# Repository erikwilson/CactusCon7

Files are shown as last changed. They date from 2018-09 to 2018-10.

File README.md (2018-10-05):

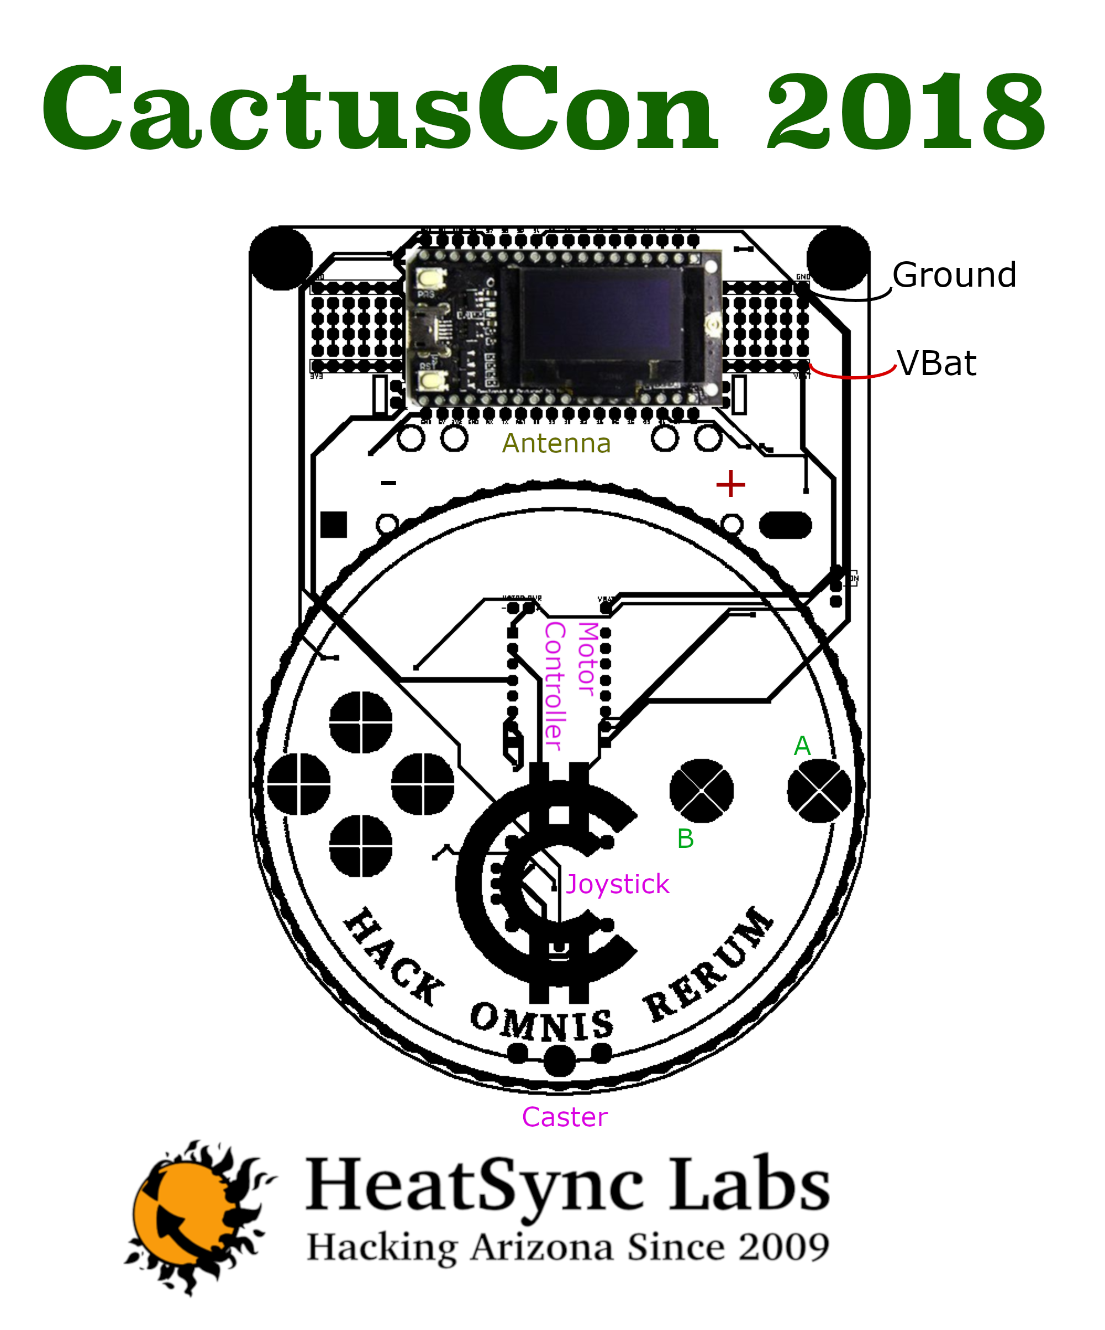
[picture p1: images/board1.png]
CactusCon 2018


# CactusCoin

## Hack All The Things

This year's badge is based around a TTGO LoRa OLED ESP32 and contains six capacitive 'buttons' driven from four sensor inputs (classic [n choose floor(n/2)](http://www.wolframalpha.com/input/?i=n+choose+floor(n%2F2)) problem). The ESP32 sports 4MB of programmable flash, WiFi, Bluetooth, and a dual core 240MHz processor, mounted on a board with a 433MHz long range radio, display, and lipo charger. It requires a single 18650 lithium ion rechargable battery. Optional circuitry supports a motor driver which operates on the same lines as the OLED by disabling screen controls when using the motor controller.  Add in some d-pad action, motors, wheels, and a jöystick. It has an access point, captive portal, websockets, and hidden secrets. The firmware was written using Arduino. It’s completely hackable. Wear it, play with it, use it, modify it, break it, learn from it.

## Volunteering

Every year countless hackers toil for endless hours to bring you this most exquisite and bespoke artisanal CactusCon experience. Please email badge@cactuscon.com if you wish to sacrifice yourself and contribute to the great process. Help build the global hacker community!

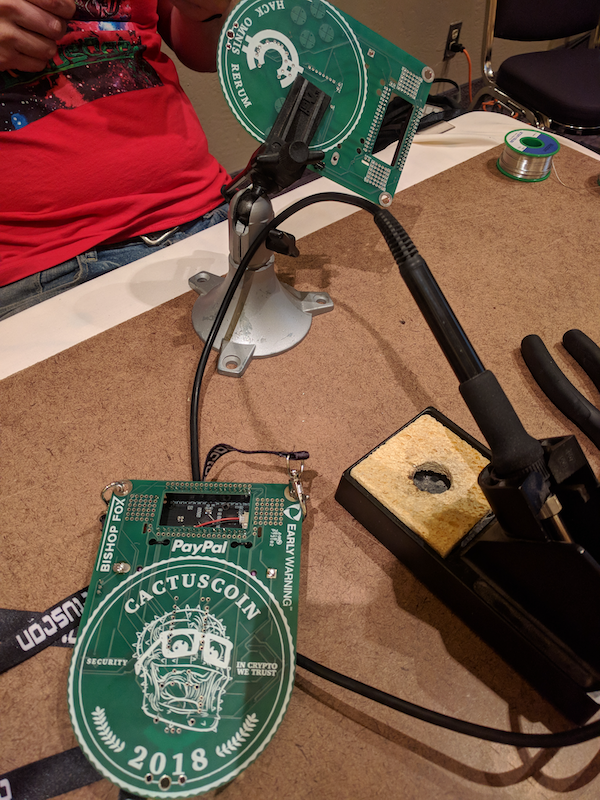
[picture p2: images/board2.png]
Volunteer


## ̶B̶u̶g̶s̶ ̶ Features and Pull Requests

Feel free to submit issues, or even better submit a pull request with extra functionality!

The coin provides a swiss army knife of utility, what can you make with it?

Pull Request

## Parts

#### basic

* 1 [TTGO LoRa OLED ESP32](https://www.aliexpress.com/item/2pcs-sets-TTGO-LORA-SX1278-ESP32-0-96-OLED-16-Mt-bytes-128-Mt-bit-433Mhz/32832523252.html)
* 2 x [18 pos female header](https://www.digikey.com/product-detail/en/PPTC181LFBN-RC/S7016-ND/810156/?itemSeq=272349209)
* 1 [battery holder](https://www.digikey.com/product-detail/en/BH-18650-PC/BH-18650-PC-ND/3029216/?itemSeq=272342283)
* 1 [switch](https://www.digikey.com/product-detail/en/MHSS1105/679-1849-ND/1949465/?itemSeq=272294708)

#### bot upgrade

* 1 [Motor driver](https://www.sparkfun.com/products/14450)
* 2 x [8 pos female header](https://www.digikey.com/product-detail/en/sullins-connector-solutions/PPTC081LFBN-RC/S7006-ND/810147)
* 1 [set Wheels](https://www.sparkfun.com/products/13259)
* 1 [set Motors](https://www.sparkfun.com/products/13302)
* 2 x [2 pos female header](https://www.digikey.com/product-detail/en/sullins-connector-solutions/PPPC021LFBN-RC/S7035-ND/810174)
* 9v [battery connector](https://www.digikey.com/products/en?keywords=36-232-ND) (optional, can use 18650 power instead)
* 1.5" x 3 [Velcro Tape](https://www.amazon.com/VELCRO-Brand-Sticky-Fasteners-Perfect/dp/B00006IC2L)
* 2 x [Zip Tie](https://www.amazon.com/dp/B01018DC96/)
* 1 [Joystick](https://www.sparkfun.com/products/9032P) (for seperate badge)

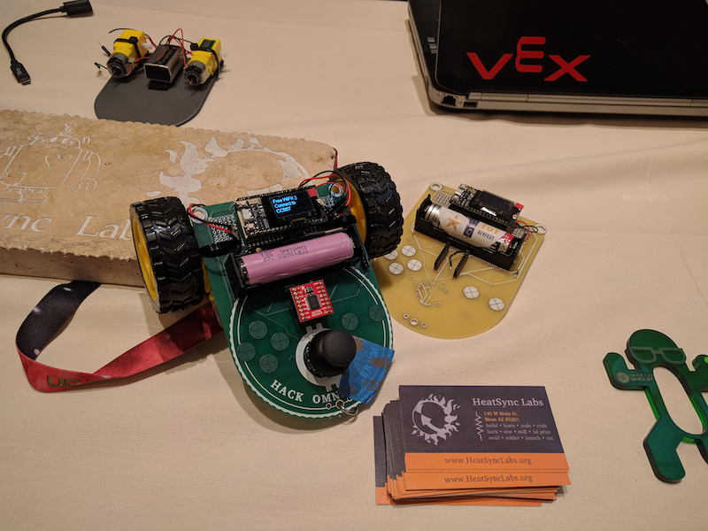
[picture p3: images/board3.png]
Spare Parts


## Additional Arduino Libraries

* https://github.com/intrbiz/arduino-crypto
* https://github.com/sandeepmistry/arduino-LoRa
* https://github.com/ThingPulse/esp8266-oled-ssd1306
* https://github.com/bblanchon/ArduinoJson
* https://github.com/me-no-dev/AsyncTCP
* https://github.com/me-no-dev/ESPAsyncWebServer
* https://github.com/me-no-dev/EspExceptionDecoder
* https://github.com/me-no-dev/arduino-esp32fs-plugin

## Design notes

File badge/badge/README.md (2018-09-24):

### Generating and flashing ID + RSA Private Key
```mkdir -p badges/1

openssl genrsa -out badges/1/private.pem 768

echo 1 > badges/1/my.id

mkspiffs-0.2.3-2-g4eae236-arduino-esp32-linux64/mkspiffs -c badges/1 -b 4096 -p 256 -s 0x16F000 badge_1.bin

esptool.py --chip esp32 --port /dev/ttyUSB0 --baud 115200 write_flash -z 0x291000 badge_1.bin
```

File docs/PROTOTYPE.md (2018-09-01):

# THE BADGE
* ESP32 LoRa & oLed board
* 18650 battery
* Joystick & Buttons?

## badge parts:
  * $12.80+ : SX1276 ESP32 w/ OLED https://wholesaler.alibaba.com/product-detail/TTGO-LORA32-868-915Mhz-SX1276-ESP32_60716800689.html
  * ~$3 : 18650 Battery https://www.imrbatteries.com/samsung-26f-18650-2600mah-5a-protected-button-top-battery/
  * $4 : Joystick https://www.sparkfun.com/products/9032
  * $2.22 : Battery Holder https://www.digikey.com/product-detail/en/mpd-memory-protection-devices/BH-18650-PC/BH-18650-PC-ND/3029216
  or <$1 https://www.digikey.com/product-detail/en/keystone-electronics/54/36-54-ND/2254090

## extra bot parts:
  * $5 : Motor driver https://www.sparkfun.com/products/14451
  * $4 : Gear motors https://www.sparkfun.com/products/13302
  * $3 : Wheels https://www.sparkfun.com/products/13259

## CACTUS COIN

* CactusCoin are generated using LoRa and proof of proximity.
* Each badge will contain a 'wallet' with a uuid and individual public/private key.
* Wallets are created/registered through on site hidden WiFi or LoRa broadcast (aka CactusCoin Node).
* Registration may contain additional personal data by encrypting it with a conference public key.
* Each badge will periodically broadcast it's wallet uuid (eg id_A).
* Nearby badges (as determined by rssi, snr, & time) will respond with pairing message & signature (id_A:id_B:id_B_sig_PKCS1).
* Requesting badge should respond with the other half of the coin request (id_B:id_A:id_A_sig_PKCS1).
* Newly generated coins are submitted with both parties cryptographic signatures of the pairing.
* The CactusCoin node will verify a coin submission using the registered public keys of the wallets, and create a new coin entry under each wallet.
* Duplicate coin submissions will/should occur, but only the first submission will update both wallets.
* Periodically badges may attempt to sync their wallet with a CactusCoin Node.
* Base stations in each room may provide real time data of attendee locations.

## CACTUS B0T

* Add on kit for badge
* Motor controller, motors, & wheels to move bot
* Remote control
  * LoRa (fast at low SF for 80 byte AES-HMAC messages)
  * BLE (poor range, maybe due to motor interference)
  * Classic Bluetooth (not tried, PS4 controller?)
  * Wifi AP Mode (implemented, captive portal & http/ws)
* Other servo control?
* Contest?!

## GAMES?
* Multi-player
  * Pandemic?
* Single-player
  * ?

## TOUCH

* Matrix Design (incomplete?!): https://github.com/espressif/esp-iot-solution/blob/master/documents/touch_pad_solution/touch_sensor_design_en.md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
* Correct equation is n choose floor(n/2), so 4 choose 2 = 6, 5 choose 2 = 10, 6 choose 3 = 20...! (where n = # capacitive sensor lines)
* Only one button active at a time, event must have # of low lines equal to the the set size (floor(n/2)), otherwise ignore. A button is composed of a set of lines, if all of the lines in the set are low the button is being pressed. 

## ARDUINO LIBRARIES

* https://github.com/intrbiz/arduino-crypto
* https://github.com/sandeepmistry/arduino-LoRa
* https://github.com/nkolban/ESP32_BLE_Arduino
* https://github.com/ThingPulse/esp8266-oled-ssd1306
* https://github.com/me-no-dev/ESPAsyncWebServer
* https://github.com/me-no-dev/AsyncTCP

## OTHER LIBRARIES OF INTEREST

* https://github.com/bluekitchen/btstack
* https://github.com/felis/USB_Host_Shield_2.0

## OTHER REFERENCES

* https://github.com/espressif/arduino-esp32/
* https://esp-idf.readthedocs.io/en/latest/
* https://media.readthedocs.org/pdf/esp-idf/latest/esp-idf.pdf
* https://www.thethingsnetwork.org/forum/uploads/default/original/2X/a/a9f3e157802318f076c7eed7c657f433aad5f1bc.jpg
* http://nicerf.com/Upload/ueditor/files/2017-06-21/LORA1278-100mW%20long%20range%20Spread%20Spectrum%20modulation%20wireless%20transceiver%20module%20V2.1-d0f02517-7b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
* https://www.ntia.doc.gov/files/ntia/publications/2003-allochrt.pdf
* https://arxiv.org/pdf/1607.08011.pdf
* https://arxiv.org/pdf/1712.02141.pdf
* http://www.sghoslya.com/p/lora_6.html
* https://docs.exploratory.engineering/lora/dr_sf/
* http://www.3glteinfo.com/lora/lorawan-frequency-bands/
* https://github.com/whitecatboard/Lua-RTOS-ESP32
* https://github.com/nodemcu/nodemcu-firmware/tree/dev-esp32

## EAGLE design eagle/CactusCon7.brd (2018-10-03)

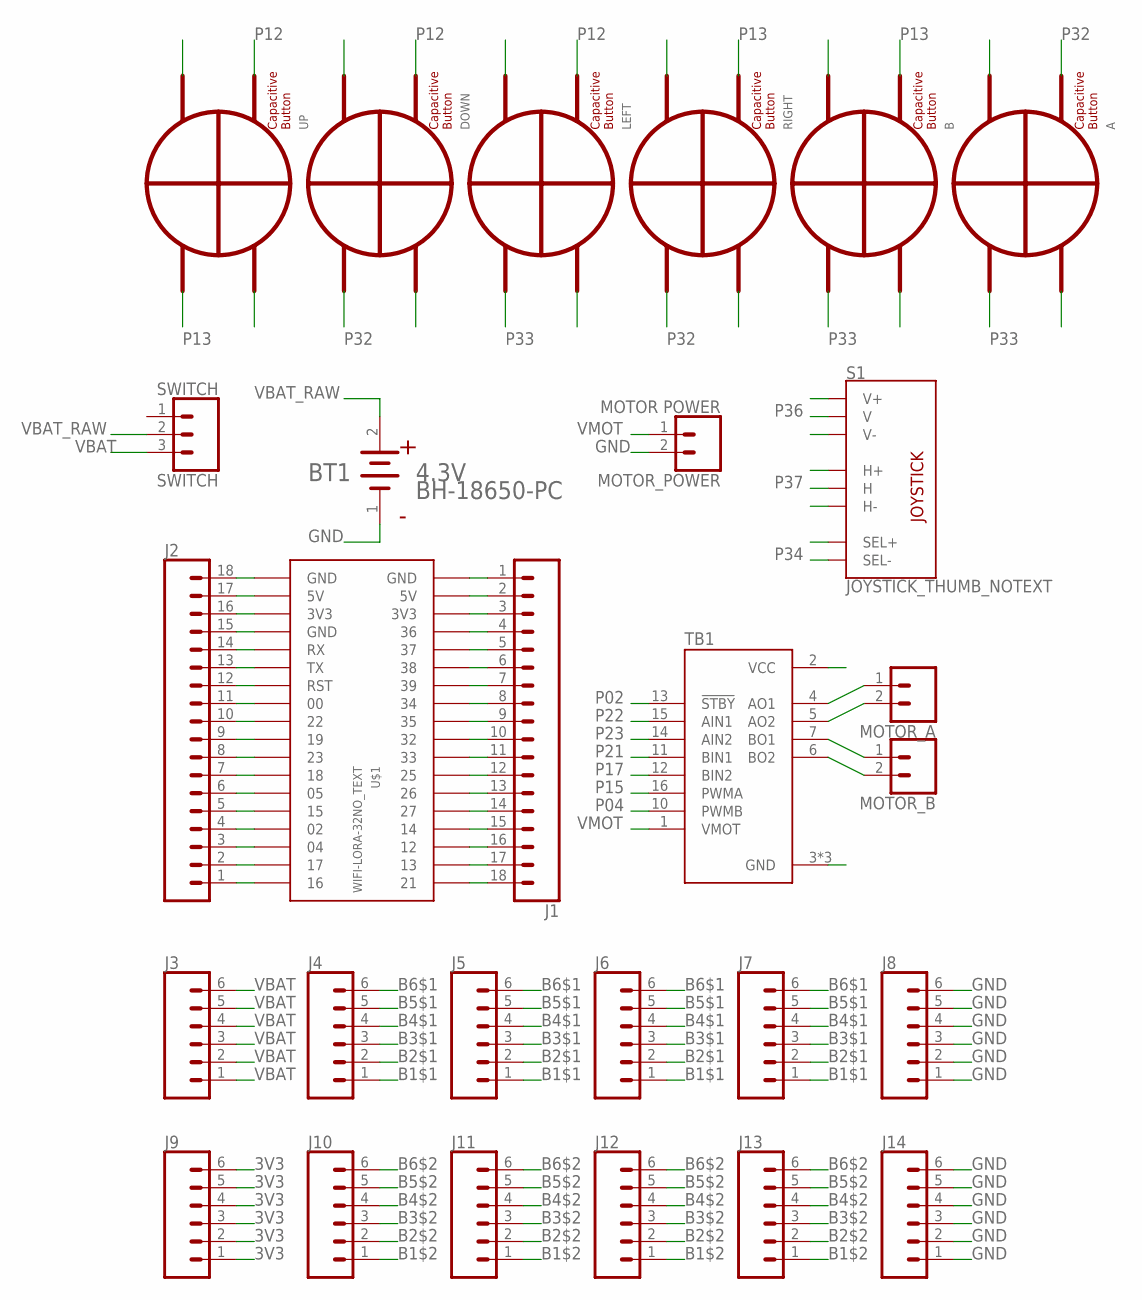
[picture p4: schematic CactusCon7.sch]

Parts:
A: BUTTON_ACTIVE_QUADNO-LOGO; BUTTON_ACTIVE_QUAD_10MM_NO_LOGO
B: BUTTON_ACTIVE_QUADNO-LOGO; BUTTON_ACTIVE_QUAD_10MM_NO_LOGO
BT1: MPD_BH-18650-PCMPD_BH-18650-PC_0_0; MPD_BH-18650-PC_0
DOWN: BUTTON_ACTIVE_QUADNO-LOGO; BUTTON_ACTIVE_QUAD_10MM_NO_LOGO
J1, J2: CONN_18; 1X18
J3, J4, J5, J6, J7, J8, J9, J10, J11, J12, J13, J14: CONN_06NO_SILK_FEMALE_PTH; 1X06_NO_SILK
LEFT: BUTTON_ACTIVE_QUADNO-LOGO; BUTTON_ACTIVE_QUAD_10MM_NO_LOGO
MOTOR_A: CONN_02; 1X02
MOTOR_B: CONN_02; 1X02
MOTOR_POWER: MOTOR POWER; 1X02
RIGHT: BUTTON_ACTIVE_QUADNO-LOGO; BUTTON_ACTIVE_QUAD_10MM_NO_LOGO
S1: JOYSTICK_THUMB_NOTEXT; JOYSTICK
SWITCH: SWITCH; 1X03
TB1: POLOLU-713ROB-14451; SHIELD_POLOLU-713
U$1: WIFI-LORA-32NO_TEXT; 2.54MM_2X18_NO_TEXT
UP: BUTTON_ACTIVE_QUADNO-LOGO; BUTTON_ACTIVE_QUAD_10MM_NO_LOGO

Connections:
3V3: J1.3, J2.16, J9.1, J9.2, J9.3, J9.4, J9.5, J9.6, S1.B1A (SEL+), S1.H1 (H+), S1.V1 (V+), TB1.2 (VCC), U$1.P$3 (3V3), U$1.P$34 (3V3)
5V: J1.2, J2.17, U$1.P$2 (5V), U$1.P$35 (5V)
AO1: MOTOR_A.1, TB1.4 (AO1)
AO2: MOTOR_A.2, TB1.5 (AO2)
B1$1: J4.1, J5.1, J6.1, J7.1
B1$2: J10.1, J11.1, J12.1, J13.1
B2$1: J4.2, J5.2, J6.2, J7.2
B2$2: J10.2, J11.2, J12.2, J13.2
B3$1: J4.3, J5.3, J6.3, J7.3
B3$2: J10.3, J11.3, J12.3, J13.3
B4$1: J4.4, J5.4, J6.4, J7.4
B4$2: J10.4, J11.4, J12.4, J13.4
B5$1: J4.5, J5.5, J6.5, J7.5
B5$2: J10.5, J11.5, J12.5, J13.5
B6$1: J4.6, J5.6, J6.6, J7.6
B6$2: J10.6, J11.6, J12.6, J13.6
BO1: MOTOR_B.1, TB1.7 (BO1)
BO2: MOTOR_B.2, TB1.6 (BO2)
GND: A.Q2, A.Q4, B.Q2, B.Q4, BT1.1 (CATHODE), DOWN.Q2, DOWN.Q4, J1.1, J2.15, J2.18, J8.1, J8.2, J8.3, J8.4, J8.5, J8.6, J14.1, J14.2, J14.3, J14.4, J14.5, J14.6, LEFT.Q2, LEFT.Q4, MOTOR_POWER.2, RIGHT.Q2, RIGHT.Q4, S1.H3 (H-), S1.V3 (V-), TB1.3 (GND), TB1.8 (GND), TB1.9 (GND), U$1.P$1 (GND), U$1.P$4 (GND), U$1.P$36 (GND), UP.Q2, UP.Q4
P00: J2.11, U$1.P$8 (00)
P02: J2.4, TB1.13 (!STBY), U$1.P$15 (02)
P04: J2.3, TB1.10 (PWMB), U$1.P$16 (04)
P05: J2.6, U$1.P$13 (05)
P12: DOWN.Q3, J1.16, LEFT.Q3, U$1.P$21 (12), UP.Q3
P13: B.Q3, J1.17, RIGHT.Q3, U$1.P$20 (13), UP.Q1
P14: J1.15, U$1.P$22 (14)
P15: J2.5, TB1.16 (PWMA), U$1.P$14 (15)
P16: J2.1, U$1.P$18 (16)
P17: J2.2, TB1.12 (BIN2), U$1.P$17 (17)
P18: J2.7, U$1.P$12 (18)
P19: J2.9, U$1.P$10 (19)
P21: J1.18, TB1.11 (BIN1), U$1.P$19 (21)
P22: J2.10, TB1.15 (AIN1), U$1.P$9 (22)
P23: J2.8, TB1.14 (AIN2), U$1.P$11 (23)
P25: J1.12, U$1.P$25 (25)
P26: J1.13, U$1.P$24 (26)
P27: J1.14, U$1.P$23 (27)
P32: A.Q3, DOWN.Q1, J1.10, RIGHT.Q1, U$1.P$27 (32)
P33: A.Q1, B.Q1, J1.11, LEFT.Q1, U$1.P$26 (33)
P34: J1.8, S1.B2A (SEL-), U$1.P$29 (34)
P35: J1.9, U$1.P$28 (35)
P36: J1.4, S1.V2 (V), U$1.P$33 (36)
P37: J1.5, S1.H2 (H), U$1.P$32 (37)
P38: J1.6, U$1.P$31 (38)
P39: J1.7, U$1.P$30 (39)
RST: J2.12, U$1.P$7 (RST)
RX: J2.14, U$1.P$5 (RX)
TX: J2.13, U$1.P$6 (TX)
VBAT: J3.1, J3.2, J3.3, J3.4, J3.5, J3.6, SWITCH.3
VBAT_RAW: BT1.2 (ANODE), SWITCH.2
VMOT: MOTOR_POWER.1, TB1.1 (VMOT)

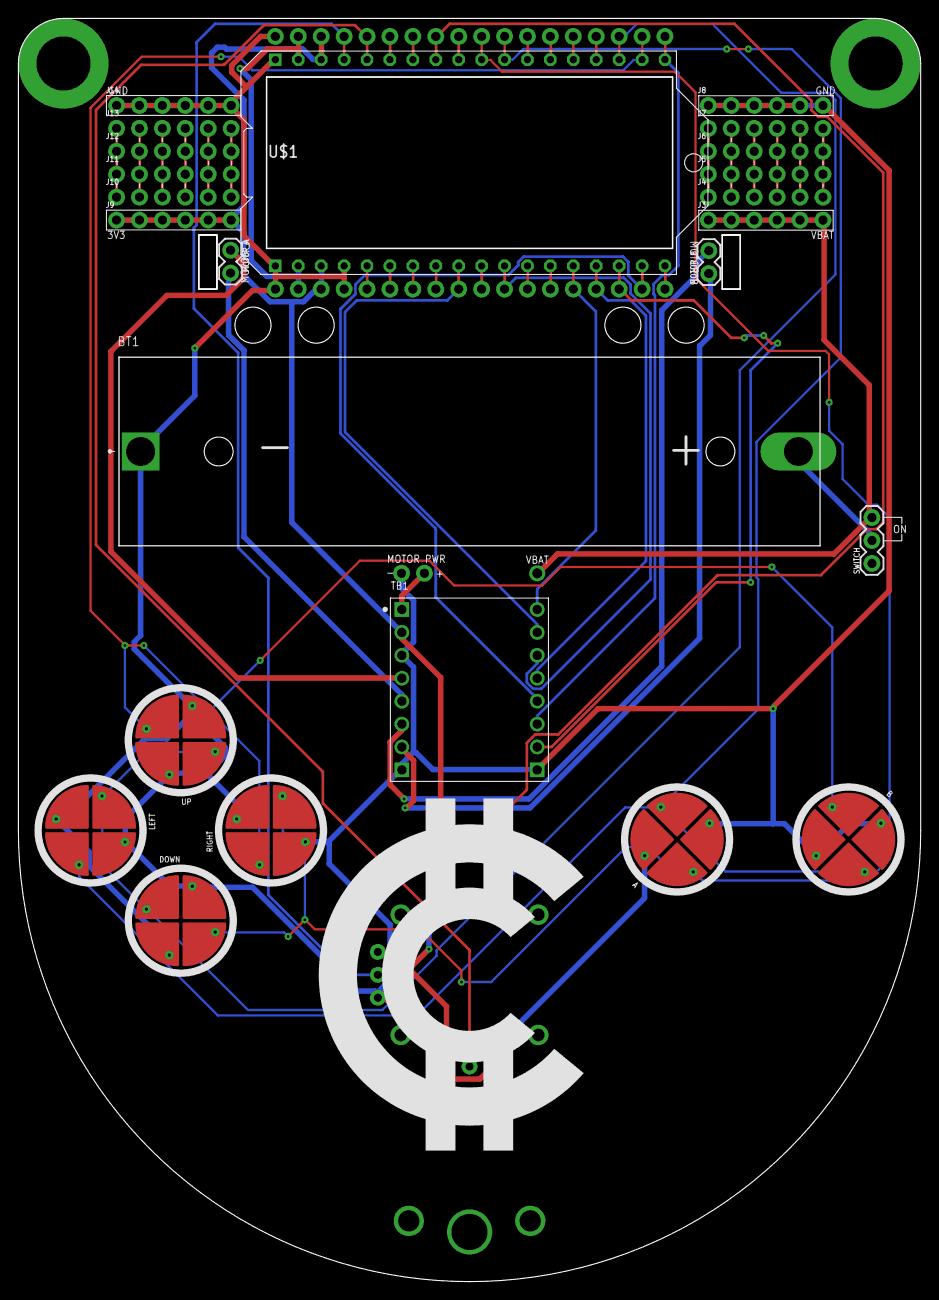
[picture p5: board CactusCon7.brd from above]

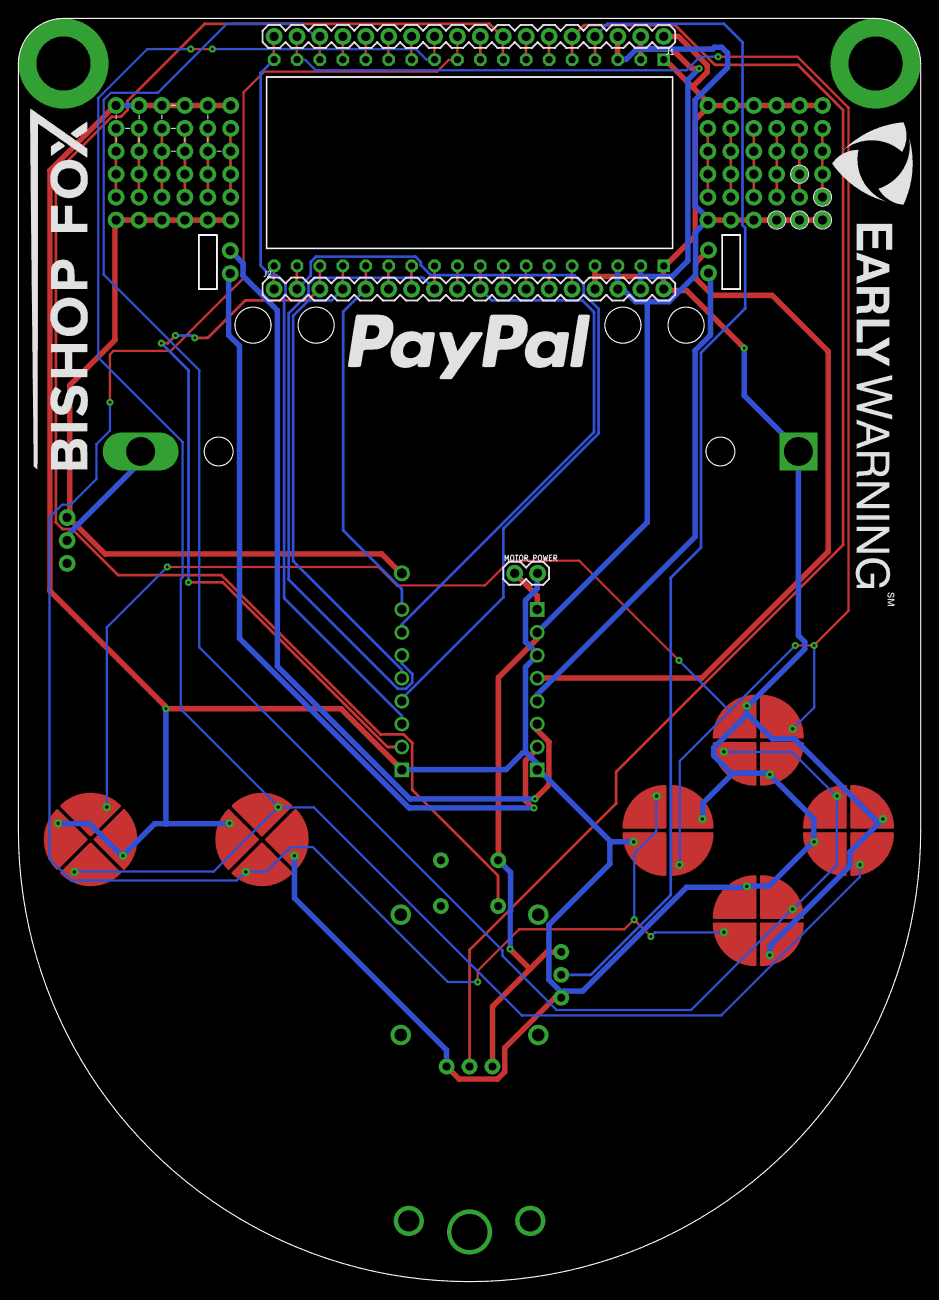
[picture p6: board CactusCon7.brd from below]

Board: 2 copper layers, 100.0 x 140.0 mm, 28 parts (3 on the bottom side), 51 nets.

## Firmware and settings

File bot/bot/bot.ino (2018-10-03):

#include <LoRa.h>
#include <Arduino.h>
#include <SSD1306.h>

#include <math.h>
#include <algorithm>

#include <SPIFFS.h>
#include <AsyncTCP.h>
#include <ESPAsyncWebServer.h>

#include <DNSServer.h>

#include "motor-crypto.h"

const byte DNS_PORT = 53;

unsigned long uptime = 0;

AsyncWebServer server(80);
AsyncWebSocket ws("/ws");

DNSServer dnsServer;

uint8_t key[] = { 'h', 'e', 'l', 'l', 'o' };
MotorCrypto motorCrypto = MotorCrypto(key, sizeof(key));

#define SS      18
#define RST     14
#define DI0     26
#define BAND    433E6  //915E6 -- 这里的模式选择中，检查一下是否可在中国实用915这个频段

#define PWMA_CH 1
#define PWMA    15
#define AI2     23
#define AI1     22
#define STDBY   2
#define BI1     21
#define BI2     17
#define PWMB    4
#define PWMB_CH 2

#define LEDC_TIMER_13_BIT  13
#define LEDC_BASE_FREQ     5000

SSD1306  display(0x3c, 4, 15);


void ledcAnalogWrite(uint8_t channel, uint32_t value, uint32_t valueMax = 255) {
  // calculate duty, 8191 from 2 ^ 13 - 1
  uint32_t duty = (8191 / valueMax) * std::min(value, valueMax);
  // write duty to LEDC
  ledcWrite(channel, duty);
}

void move(uint8_t mode, uint8_t motorL, uint8_t motorR) {
  uptime = millis();

  if (mode == 0) {
    digitalWrite(STDBY, LOW);
  } else {
    digitalWrite(STDBY, HIGH);
  }
  if (mode == 1) {
    digitalWrite(AI1, HIGH);
    digitalWrite(AI2, LOW);
    digitalWrite(BI1, HIGH);
    digitalWrite(BI2, LOW);
  }
  if (mode == 2) {
    digitalWrite(AI1, LOW);
    digitalWrite(AI2, HIGH);
    digitalWrite(BI1, HIGH);
    digitalWrite(BI2, LOW);
  }
  if (mode == 3) {
    digitalWrite(AI1, HIGH);
    digitalWrite(AI2, LOW);
    digitalWrite(BI1, LOW);
    digitalWrite(BI2, HIGH);
  }
  if (mode == 4) {
    digitalWrite(AI1, LOW);
    digitalWrite(AI2, HIGH);
    digitalWrite(BI1, LOW);
    digitalWrite(BI2, HIGH);
  }
  ledcAnalogWrite(PWMA_CH, motorL);
  ledcAnalogWrite(PWMB_CH, motorR);
}


void onReceive(int packetSize) {
  // Serial.println("Got LoRa DATA!");
  uint8_t data[packetSize] = {};
  // read packet
  for (int i = 0; i < packetSize; i++) {
    data[i] = LoRa.read();
  }

  if (packetSize == 80) {
    MotorEncrypted &encrypted = *(MotorEncrypted*)&data;
    if (motorCrypto.verifyHmac(encrypted)) {
      MotorMessage message = motorCrypto.decrypt(encrypted);
      if (motorCrypto.validateMessage(message)) {
        move(message.mode,message.motorL,message.motorR);
      }
    }
  }
}

void onWsEvent(AsyncWebSocket * server, AsyncWebSocketClient * client, AwsEventType type, void * arg, uint8_t *data, size_t len){
  //Handle WebSocket event
  uint16_t *posData = (uint16_t*)data;
  if (len != 8) return;

  int maxX = posData[2];
  int maxY = posData[3];
  int avgX = maxX/2;
  int avgY = maxY/2;
  int x = posData[0];
  int y = maxY - posData[1];

  uint8_t *motor = getMotorMove(x,y,avgX,avgY,0,0,maxX,maxY);
  move(motor[0],motor[1],motor[2]);
}

uint8_t* getMotorMove(
  int AX,
  int AY,
  int avgX,
  int avgY,
  int deltaX,
  int deltaY,
  int maxX,
  int maxY
) {

  static uint8_t result[3];

  double x = 0;
  double y = 0;

  if (fabs(avgX-AX) > deltaX || fabs(avgY-AY) > deltaY) {
    if (AX < avgX) {
      x = double(AX - avgX) / avgX;
    } else {
      x = double(AX - avgX) / (maxX - avgX);
    }
    if (AY < avgY) {
      y = double(AY - avgY) / avgY;
    } else {
      y = double(AY - avgY) / (maxY - avgY);
    }
  }

  const double angleJ = atan2(y,x) * 180. / M_PI;

  const double r = std::max(fabs(x),fabs(y));
  const double newX = r * cos(angleJ * M_PI / 180);
  const double newY = r * sin(angleJ * M_PI / 180);

  const double angleM = r > 0 ? (angleJ < 45 ? 360. : 0.) + angleJ - 45 : 0;

  const double powerL = r * cos(angleM * M_PI / 180);
  const double powerR = r * sin(angleM * M_PI / 180);

  double scale = 1;
  double mx = 0;
  double my = 0;
  double angleMr = angleM * M_PI / 180;

  if (x<=0 && y>0 || x>=0 && y<0) {
    my = 1;
    mx = 1./tan(angleMr);
  }
  if (x>0 && y>=0 || x<0 && y<=0) {
    mx = 1;
    my = tan(angleMr);
  }
  scale = sqrt(pow(mx, 2) + pow(my, 2));

  const int motorBL = scale*fabs(powerL)*265;
  uint8_t motorL = 0;
  if (motorBL>255) motorL = 255;
  else if (motorBL>0) motorL = motorBL;

  const int motorBR = scale*fabs(powerR)*265;
  uint8_t motorR = 0;
  if (motorBR>255) motorR = 255;
  else if (motorBR>0) motorR = motorBR;

  uint8_t mode = 0;
  if (r > 0) {
    if (powerL<=0 && powerR<=0) mode = 4;
    if (powerL>=0 && powerR<=0) mode = 3;
    if (powerL<=0 && powerR>=0) mode = 2;
    if (powerL>=0 && powerR>=0) mode = 1;
  }

  result[0] = mode;
  result[1] = motorL;
  result[2] = motorR;

  return result;
}

void setupLora() {
  LoRa.setPins(SS, RST, DI0);

  if (!LoRa.begin(BAND)) {
    Serial.println("Starting LoRa failed!");
    while (1);
  }
  LoRa.setSignalBandwidth(500e3);
  LoRa.setPreambleLength(8);
  LoRa.setSpreadingFactor(7);
  LoRa.setSyncWord(0x7B);           // ranges from 0-0xFF, default 0x34, see API docs
  // register the receive callback
  // LoRa.onReceive(onReceive);
  // // put the radio into receive mode
  // LoRa.receive();

  Serial.println("LoRa Initial OK!");
}

void setupWifi() {
  const char *ssid = "CCB07";

  WiFi.mode(WIFI_AP);
  WiFi.softAP(ssid);
  IPAddress myIP = WiFi.softAPIP();
  Serial.print("AP IP address: ");
  Serial.println(myIP);

  dnsServer.setErrorReplyCode(DNSReplyCode::NoError);
  dnsServer.start(DNS_PORT, "*", myIP);

  SPIFFS.begin();

  ws.onEvent(onWsEvent);
  server.addHandler(&ws);
  server.serveStatic("/", SPIFFS, "/www/");
  server.onNotFound(redirect);

  server.begin();
}

void setup() {
  Serial.begin(115200);
  while (!Serial); //If just the the basic function, must connect to a computer

  pinMode(16, OUTPUT);
  digitalWrite(16, LOW);    // set GPIO16 low to reset OLED
  delay(50);
  digitalWrite(16, HIGH); // while OLED is running, must set GPIO16 in high

  display.init();
  display.flipScreenVertically();

  display.clear();
  display.setTextAlignment(TEXT_ALIGN_LEFT);
  display.setFont(ArialMT_Plain_16);

  display.drawStringMaxWidth(0, 0, 128, "Free WiFi! :)");
  display.drawStringMaxWidth(0, 18, 128, "Connect to CCB07");

  display.display();

  pinMode(AI1, OUTPUT);
  pinMode(AI2, OUTPUT);
  pinMode(BI1, OUTPUT);
  pinMode(BI2, OUTPUT);
  pinMode(STDBY, OUTPUT);

  pinMode(PWMA, OUTPUT);
  pinMode(PWMB, OUTPUT);

  ledcSetup(PWMA_CH, LEDC_BASE_FREQ, LEDC_TIMER_13_BIT);
  ledcAttachPin(PWMA, PWMA_CH);

  ledcSetup(PWMB_CH, LEDC_BASE_FREQ, LEDC_TIMER_13_BIT);
  ledcAttachPin(PWMB, PWMB_CH);

  setupWifi();
  setupLora();
}

void redirect(AsyncWebServerRequest *request){
  //Handle Unknown Request
  request->redirect("http://robutts/");
}

void parsePacket() {
  int packetSize = LoRa.parsePacket(80);
  if (packetSize > 0) {
    onReceive(packetSize);
  }
  if ((millis() - uptime) > 1000) {
    move(0,0,0);
  }
}

void loop() {
  dnsServer.processNextRequest();
  parsePacket();
}

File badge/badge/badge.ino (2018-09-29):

#include <HTTPClient.h>
#include <SPIFFS.h>
#include <Ticker.h>
#include <SPI.h>
#include <LoRa.h>
#include <WiFi.h>
#include <SSD1306.h>
#include "Font.h"
#include "mbedtls/pk.h"
#include "mbedtls/error.h"
#include "mbedtls/entropy.h"
#include "mbedtls/ctr_drbg.h"
#include "mbedtls/md.h"
#include "mbedtls/sha256.h"
#include "mbedtls/base64.h"

#include "config.h"
#include "credentials.h"
#include "CDP.h"

SSD1306 display(0x3c, 4, 15);
Ticker gbpTimer;
Ticker TXLogTimer;
int coinCounter = 0;
uint16_t myBadgeID = 0;
char myName[MAX_NAME_LENGTH];
bool sendGBP = false;
bool TXLogFlush = false;
bool catastrophicFailure = false; 
mbedtls_pk_context badgePK;
mbedtls_pk_context nodePK;
mbedtls_entropy_context entropy;
mbedtls_ctr_drbg_context ctr_drbg;

void triggerGBP() {
  sendGBP = true;
}

void triggerPendingTXLogFlush() {
  TXLogFlush = true;
}

void setup() {
  Serial.begin(115200);
  while (!Serial);
  Serial.println(F("CactusCoinBadge v1.1"));
  btStop();

  pinMode(16, OUTPUT);
  digitalWrite(16, LOW);    // set GPIO16 low to reset OLED
  delay(50);
  digitalWrite(16, HIGH); // while OLED is running, must set GPIO16 in high

  touchSetCycles(0xA00, 0x2000);
  setupPrintable();

  display.init();
  display.flipScreenVertically();
  display.setTextAlignment(TEXT_ALIGN_LEFT);
  display.setBrightness(20);

  display.clear();
  display.setFont(Roboto_Light_15);
  display.drawStringMaxWidth(0, 24, 128, "Connecting...");
  display.display();

  if (!setupFS()) {
    catastrophicFailure = true;
    return;
  }

  if (!setupCrypto()) {
    catastrophicFailure = true;
    return;
  }
  drainSignedCoinPendingTXLogOnFS();
  turnWiFiOnAndConnect();

  if (!registerBadge()) {
    turnWiFiOff();
    catastrophicFailure = true;
    return;
  }
  
  display.clear();
  display.setFont(Roboto_Light_15);
  display.drawStringMaxWidth(0, 12, 128, "Reticulating Splines...");
  display.setFont(Roboto_Light_11);
  display.display();

  drainSignedCoinPendingTXLogOnFS();
  refreshLocalCoinListFromAPI();

  turnWiFiOff();
  
  LoRa.setPins(18, 14, 26);
  if (!LoRa.begin(433E6)) {
    Serial.println(F("Starting LoRa failed!"));
    while (1);
  }
  LoRa.setTxPower(BADGE_TX_POWER);
  Serial.println(F("LoRa started..."));

  gbpTimer.attach(random(60, 120), triggerGBP);
  TXLogTimer.attach(TXLOG_FLUSH_SEC, triggerPendingTXLogFlush);

  updateDisplay();
}

void updateDisplay() {
  char badgeIDMessage[20], nameMessage[MAX_NAME_LENGTH + 6], coinMessage[13];
  if (catastrophicFailure) {
    display.setFont(ArialMT_Plain_10);
    display.clear();
    display.drawStringMaxWidth(0, 0, 128, F("Problem bootstrapping badge.  Get closer to the WiFi and press the restart button (RST) next to the USB port."));
    display.display();
    return;
  }
  
  sprintf(badgeIDMessage, "Badge ID: %d", myBadgeID);
  sprintf(nameMessage, "Name: %s", myName);
  sprintf(coinMessage, "Coins: %d", coinCounter);
  
  display.clear();
  display.setFont(Roboto_Light_15);
  display.drawString(0, 0, badgeIDMessage);
  display.drawString(0, 21, nameMessage);
  display.drawString(0, 42, coinMessage);
  display.display();
}

void processPacket() {
    int packetSize = LoRa.available();
    byte packet[packetSize];
    byte *packetPtr = &packet[1];
    char json[MAX_JSON_SIZE];
    uint16_t broadcasterID;
    SignedCoin signedCoin;

    for (int i = 0; i < packetSize; i++)
      packet[i] = LoRa.read();
      
    //Serial.print(F("LORA: Got a packet of type "));
    //Serial.printf("%02X\r\r\n", packet[0]);
    
    switch (packet[0]) {
      case CDP_GLOBALBROADCAST_TYPE:
        if (isValidGlobalBroadcast(packetPtr, packetSize))
          transmitCoinSigningRequest(myBadgeID, packetPtr, packetSize);
          
        break;
        
      case CDP_COINSIGNINGREQUEST_TYPE:
        if (isValidCoinSigningRequest(packetPtr, packetSize)) {
          transmitSignedCoin(myBadgeID, packetPtr, packetSize);
        }
        break;
        
      case CDP_SIGNEDCOIN_TYPE:
        if (isValidSignedCoin(packetPtr, packetSize)) {
          jsonifySignedCoin(packetPtr, packetSize, json, MAX_JSON_SIZE);
          broadcasterID = getBroadcasterIDFromBytes(packetPtr, packetSize);

          turnWiFiOnAndConnect();
          if (!submitSignedCoinToAPI(json))
            storeUnsentSignedCoinOnFS(broadcasterID, json);
          else
            storeCompletedCoinOnFS(broadcasterID);
          turnWiFiOff();
        }
    }
}

void loop() {
  int packetSize = LoRa.parsePacket();

  if (packetSize) {
    processPacket();
  }

  if (sendGBP) {
    transmitGlobalBroadcast(myBadgeID);
    sendGBP = false;
  }

  if (TXLogFlush) {
    turnWiFiOnAndConnect();
    drainSignedCoinPendingTXLogOnFS();  // always drain coins before doing an FS update, otherwise problems can abound
    refreshLocalCoinListFromAPI();
    turnWiFiOff();
    TXLogFlush = false;
  }

  updateDisplay();
}

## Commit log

2018-08-22 fixed for python3 and added exception wrapping for invalid signatures on verify
    [crypto.py]
2018-08-31 fixed bug where name changes were causing points to accumulate
    [badge.py]
2018-09-20 first pass of packing/unpacking with just type casting... appears to be working well, but nested structs are having an issue.
    [CDP.ino, RegisterBadge.ino]
2018-09-25 somehow... this is working now... pretty sure void casting structs across the wire was a mistake now... oh well.
    [CDP.ino, CactuscoinAPI.ino, Crypto.ino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]
2018-09-26 argh, just when i thought i had this fixed i discovered more bugs... most squashed, but need to decide what happens when a duplicate CSR shows up
    [CDP.ino, FS.ino]
2018-09-26 sample touch code
2018-09-26 fixed duplicate csr issue, few other fs issues, and now close to having it able to submit... some stack overflow issue though when signing message for api, will look at it when i get back
    [CDP.ino, CactuscoinAPI.ino, FS.ino]
2018-09-27 mother of all updates.. fixed lots of bugs, adjusted api to match badge json, basic use case is now fully functional!! still needs some tuning and there is one odd bug where badges still transmit csr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
    [CDP.ino, CactuscoinAPI.ino, Crypto.ino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]
2018-09-28 fixed some bugs, seems there are a couple more
    [RegisterBadge.ino]
2018-09-29 fixed bugs in the backend
    [badge.py, coin.py, coin_paginated.py]
2018-09-29 lots o bug fixes, should be solid now.. i think.. maybe
    [CDP.ino, CactuscoinAPI.ino, FS.ino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]
2018-09-29 added support for sponsorship whoring :) and fixed ids > 1 byte
    [FS.ino, coin.py]
2018-09-29 maybe this is the bug?
    [FS.ino]

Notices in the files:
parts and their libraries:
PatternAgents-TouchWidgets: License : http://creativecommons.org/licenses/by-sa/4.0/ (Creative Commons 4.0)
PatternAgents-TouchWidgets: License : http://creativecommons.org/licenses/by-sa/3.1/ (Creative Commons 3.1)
